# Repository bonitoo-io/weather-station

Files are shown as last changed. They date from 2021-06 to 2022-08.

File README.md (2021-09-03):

# Weather Station

## Description

Weather station is a smart IoT device that shows various information on the embedded OLED display.



It can show the following information:

- Actual `time and date` (in analog and digital format). Accurate time and date is automatically loaded from NTP time service.
- Current `temperature` and `humidity` using internal sensor
- `Temperature chart` showing trend for the last 90 minutes. If the temperature is stored into InfluxDB, after rebooting this temperature history is fully loaded back from the InfluxDB.
- `Current weather` - shows weather icon, temperature, and wind speed. It automatically identifies approximate location for weather service based on assigned IP address. The weather is updated once per hour.
- `Weather forecast` for the next three days at noon - shows weather icon, temperature, wind speed and wind direction
- `Moon phase`, moon set/rise and sun set/rise time

To get time, location, weather forecasts and other information, the weather station requires Internet connection over WiFi. The temperature and humidity from the internal sensor can be also automatically stored into InfluxDB to analyze history.
Information on the OLED display can be localized. Currently we support English and Czech language. The weather station firmware is checked once per day and in case of new firmware, it is automatically updated from the centralized repository.
The weather station is powered via USB cable.

## QuickStart Guide

### WiFi Connection

Weather station requires WiFi network (to get time/date, weather forecast, to store temperature/humidity history, etc.)
Because it does not have any keyboard to configure it, the Weather Station requires your mobile phone or computer to set it up. It creates own WiFi hotspot to connect it by your device.

WiFi Configuration steps:

1) Plug USB cable into the Weather Station to power on. If your computer shows missing driver message, you can ignore it.
2) The Weather Station shows a name of WiFi network for configuration that is created by the Weather Station itself. If you see Connecting WiFi message, and the Weather Station is unable to connect, please wait for 30 seconds to show the WIFi network.
3) Connect your phone or laptop to this WiFi. No password is required.
4) If the phone or laptop shows that the WiFi does not offer Internet connection, please ignore it and confirm the connection - the WiFi was created just for configuration of the Weather Station
5) A configuration page should be displayed automatically. If not, open your browser and type <http://1.1.1.1> In both cases you should see Weather Station web page.
6) Select your home/company WiFi network from the list that Weather Station can connect. The list is sorted from the strongest one. If your WiFi network is hidden, please enter the name (SSID) manually via link. Note that only 2.4GHz WiFi networks are supported.
7) Enter your WiFi network password, if exists
8) Click to Save button
9) The Weather Station should reboot and sync all the data via the newly configured WiFi. Your phone or laptop should be disconnected automatically.
10) If you see again the same message on the OLED display as in the second step, the network name or password has been entered incorrectly. Please repeat the process.

### InfluxDB Configuration

If you want to record your temperature and humidity measured by the Weather Station sensor, you need to setup an InfluxDB account.
You can also use a free [InfluxDB Cloud](https://cloud2.influxdata.com) account, or you can deploy your own InfluxDB instance. Additionally, the Weather Station also records into InfluxDB some run-time measurements like free memory, heap fragmentation, reboot reason, firmware version or uptime.
The following steps require a Weather Station with properly connected WiFi network (see the previous chapter).

InfluxDB Configuration steps:

1) Wait for the last page on the OLED display
2) Enter into the web browser on your phone or computer the address from the last page
3) Your browser should show Weather Station web page. Note that your phone or computer must be connected to the same WiFi network as the Weather station otherwise you cannot open it.
4) Select InfluxDB Settings from the menu
5) Fill all required fields (specific bucket must be created in the InfluxDB as well as token with read/write access)
6) Click to Save button
7) If you see an exclamation mark icon in the top left corner of the OLED display, the fields are not entered correctly, or Weather Station lost the connection to the InfluxDB.

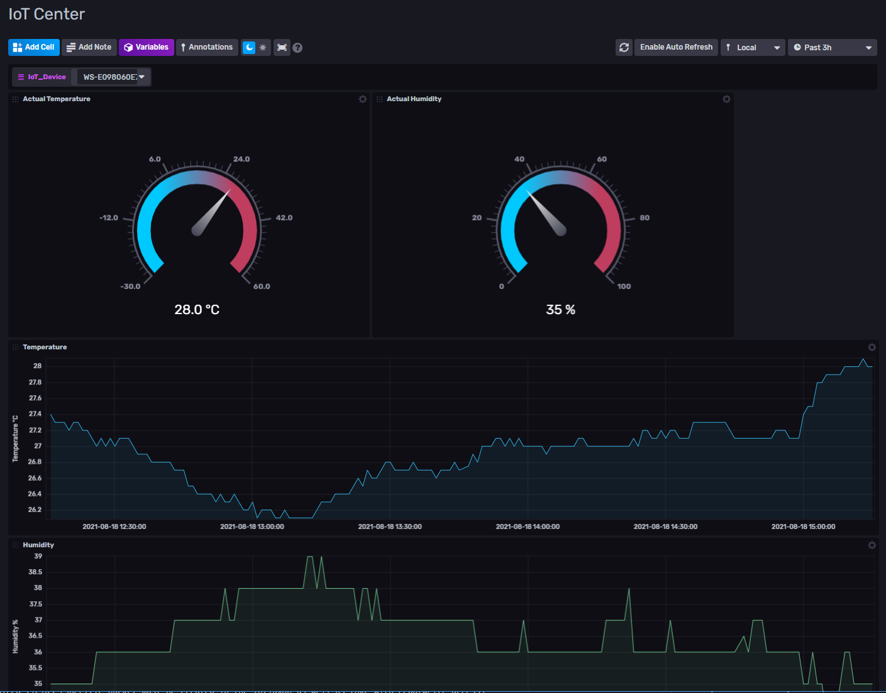
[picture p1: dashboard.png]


## Technical part

### Hardware

Developed for Weather Station DIY kit that consists of:

- `IoT Platform` - [ESP8266](https://docs.ai-thinker.com/_media/esp8266/docs/esp-12f_product_specification_en.pdf)
- `Display` - OLED 0,96" 128x64 [SSD1306](https://cdn-shop.adafruit.com/datasheets/SSD1306.pdf)
- `Temperature and Humidity sensor` - [DHT11](https://www.mouser.com/datasheet/2/758/DHT11-Technical-Data-Sheet-Translated-Version-1143054.pdf)

### Source Code

The Weather Station project consists of three sub-projects:

1) [Full Arduino Implementation](arduino/WeatherStation#weather-station)
2) [Basic Micropython Implementation](micropython)
3) [Case for 3D Printer](case)

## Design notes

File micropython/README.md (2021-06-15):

# Micropython ESP8266 Weather Station

## Description

This is PoC Weather Station project written in Micropython language for ESP8266 device. 
It is designed to show possibilities and limits of current Micropython firmware 
and implement a simple InfluxDB2 Client with timestamp support. In order to have relatively accurate timestamps it also 
implements periodic RTC synchronisation with NTP server. OLED display 
(using included micropython's DHT11 and SSD1306 driver) shows DHT11 data with random screen coordinates
to avoid screen burn-in.



It consists of:
  - `config.json` - JSON objects with configuration.
  - `webrepl_cfg.py` - WebREPL configuration. 
  - `boot.py` - Micropython boot file.
  - `main.py` - Micropython main code.
  - `wm.py` - Wi-Fi Manager to allow automatic wi-fi connections according to _known_networks_ entries in `config.json`. 
  In case of no _known_networks_ available it is also capable of running private access point with WebRepl.

## How to run the Micropython WeatherStation

1) Flash the firmware.
2) Install python shell.
3) Update `config.json`:
    - configure wi-fi connection details (With Internet connection for NTP routine)
    - add your influxdb2 connection details
    - adjust intervals
4) Set password for WebREPL connection in `webrepl_cfg.py`  
4) Adjust Point object parameters to reflect your infrastructure:
   ```python
   def publish(data, client):
    point = Point("dht11") \
        .field("temperature", data["t"]) \
        .field("humidity", data["rh"]) \
        .tag("location", "office") \
        .time(time.time(), WritePrecision.S)
   ...
   ```
   - Available functions for getting time:
     https://docs.micropython.org/en/latest/library/utime.html#module-utime
     
5) Connect to the device.
6) Put all files into device.
7) Restart WeatherStation device.

## Firmware

Before execution of any micropython code each ESP device must be erased and flashed with latest micropython firmware.

How-To Guide: https://micropython-docs-esp32.readthedocs.io/en/esp32_doc/esp8266/tutorial/intro.html#intro

Download page: https://micropython.org/download/esp8266/

## Remote shells

Used to manipulate with files and run python code over serial connection.

Top 3 shells to choose from:

Ampy: https://github.com/scientifichackers/ampy

Mpfshell: https://github.com/wendlers/mpfshell

Rshell: https://github.com/dhylands/rshell

## Caveats

### SSL error (OSError -40):

With Micropython's ESP8266 port version (=< 1.15) the https post to cloud2.influxdata.com fails with OSError -40. 
The issue seems to be that certain certificate types are not supported in axtls of underlining ESP-SDK.
Only solution seems to be wait until micropython will be supporting newer ESP-SDK with mbedtls, 
or compile your own micropython firmware with a hack described in:  
https://github.com/micropython/micropython-lib/issues/400

More details: https://docs.micropython.org/en/latest/esp8266/general.html#ssl-tls-limitations

### NTP time in UTC only:

There's currently no timezone support in MicroPython (1.15) for ESP8266 port, and the RTC is set in UTC time.

### Internal Real-time Clock limits:

RTC in ESP8266 has very bad accuracy, drift may be seconds per minute. 
As a workaround, to measure short enough intervals you can use utime.time(), etc. 
and/or synchronise time via ntp regularly. 
Due to limitations of the ESP8266 chip the internal real-time clock (RTC) will overflow every 7:45h. 
If a long-term working RTC time is required then time() or localtime() must be called at least once within 7 hours. 
MicroPython will then handle the overflow.

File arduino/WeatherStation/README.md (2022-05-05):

# Weather Station

Weather station with OLED and WiFi (using ESP8266, SSD1306, and DHT11) with InfluxDB support

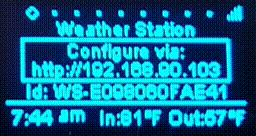
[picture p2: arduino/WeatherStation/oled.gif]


## Arduino IDE

* Into "File/Preferences/Additional Boards Manager URLs:" add "http://arduino.esp8266.com/stable/package_esp8266com_index.json"
* Menu Tools/Board:/Boards Manager select esp8266 and Install it
* Select Tools/Board: NodeMCU 1.0 (ESP-12E Module)
* Connect weather station via USB
* Select Tools/Port: the serial port created by the weather station
* Open WeatherStation.ino file
* Update OPEN_WEATHER_MAP_API_KEY
* Click the secon icon in the toolbar "Upload"

* Create iot_center bucket inside InfluxDB

## Required Libraries

Libraries are accessible via Library manager or must installed manually, if source URL is provided.
Indentation means transitive dependency, but such a library must be installed as well.

* ESP8266 and ESP32 OLED driver for SSD1306 displays (by ThingPulse, Fabrice Weinberg)
* ESP8266 Weather Station (by ThingPulse) optimized version - from https://github.com/bonitoo-io/esp8266-weather-station branch [all-fixes](https://github.com/bonitoo-io/esp8266-weather-station/tree/all-fixes)
  * Json Streaming Parser (by Daniel Eichhorn)
* Support for Sensirion's humidity and temperature sensors - Supported sensors: SHTC1, SHTC3, SHTW1, SHTW2, SHT3x-DIS (I2C), SHT85, SHT3x-ARP, SHT4x
  * arduino-sht
* ESP8266 Influxdb (by Tobias Schürg, InfluxData)
* ESP Github Updater - from https://github.com/bonitoo-io/ESP-Github-Updater
* ESPAsyncWebServer - from https://github.com/bonitoo-io/ESPAsyncWebServer/ branch [feat/global_filter](https://github.com/bonitoo-io/ESPAsyncWebServer/tree/feat/global_filter)
  * ESPAsyncTCP - from https://github.com/bonitoo-io/ESPAsyncTCP

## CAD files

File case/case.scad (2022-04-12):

// case Roman

// won't change result just render faster but can result in visual bugs in preview                                       ------------
fast_render = true; 

render_parts = "all"; // ["all": All, "box": Box, "cover": Cover, "button": Button, "none": none, "display": Display test, "cover-test": Cover test , "hexbox1": Hexbox vizualization, "hexbox2": Hexbox vizualization 2]

/* [Shell] */

shell_width = 1.5; // [.2:.1:3]

outer_fillet = 3.3;
inner_fillet = 1;

// hex recomended logo_position_x = 14.5;
logo_position_x = 1; // [-12:.5:28]
// hex recomended logo_position_y = -24.2;
logo_position_y = -24; // [-28:.5:12]
// hex recomended logo_scale = 1;
logo_scale = 1.15; // [.5:.01:1.5]

// previous usb_hole = [9.5, 3.8];
usb_hole = [14.2, 5.5];

/* [Main board] */
corner_width = 5;
corner_support = 7;
board_height_modificator = -.5;

/* [Hex] */
hex_enabled = true;

hex_front = false;
hex_right = true;
hex_left = true;
hex_top = false;
hex_bot = false;
hex_sensor_wall = false;

hex_dist = 1.25;
shell_critical_places_dist = 1.5;

/* [Button] */
// button changes based on shell width
button_use_shell_width = true; 
// button stand out when use shell width enabled
button_height_shell_added = .2;
// bottom cylinder of button, this changes socket too
button_height = 4;
// height of securing cylinder preventing button from falling out
button_height2 = 3;
// width of button visible from outside
button_width = 3;
// upper width of securing cylinder, must be higher than button width
button_width2 = 4;
// width of slip-preventing button to board contact
button_width3 = 4;
// full height of button, can be dependent on button_use_shell_width
button_height_full = 24;
// distance between button and socket
button_clearance = .15;
// how strong is button socket
button_socket_width = .8;

/* [Ventilation] */
vent_top = false;
vent_side = false;
vent_upper_width = 7;
vent_upper_dist_side = 2;

/* [Sensor wall] */
sensor_wall_width = 1.5;
sensor_wall_hole_width = 3;
sensor_wall_hole_height = 50;

/* [Cover] */
cover_lock_clearance = [ 2, .1, .4 ];
use_cover_text = false;
cover_frame_polygon = [[0, 0], [3, 0], [0, 5]];
// y=0 will use shell width
box_cover_lock = [20, 0, .8]; 
batch_number = "2203";

module _() {}
// vnitřní rozměry v mm
w = 58.5;  // inner Width
d = 58.5;  // depth
h = 29;    // height

main_board_width = 43.75;
main_board_depth = 57;

logo_position = [logo_position_x, logo_position_y];

box_cover_lock_real = [box_cover_lock[0], box_cover_lock[1] == 0 ? shell_width : box_cover_lock[1], box_cover_lock[2]];

if (render_parts == "all") {
  translate([-(w / 2) - shell_width - 1, 0, 0])
  {
    ws_box(hex= hex_enabled);

    translate([w / 2 + shell_width + button_width2 + 2, h + button_width2 + 2, 0])
      button();

    translate([w+shell_width+2,0,0])
      cover();
  }
}

if (render_parts == "box") {
  ws_box(hex= hex_enabled);
}

if (render_parts == "cover") {
  cover();
}

if (render_parts == "button") {
  button();
}

*
translate([-15,-15,0]) {
  difference() {
    union () {
      cube([30,30,30]);

      translate([30+.3, 0, 0])
      translate([0, 1, 1])
      rotate(-90, [0,1,0])
      scale([.8, .8])
      linear_extrude(.3+1)
        {
          import("logo_influx.svg");
  
          mirror([0,1,0])
          rotate(-90)
              text(".3 out side", size=2, $fn=1);
        }

      translate([1, 1, 30 - 1])
      scale([.8, .8])
      linear_extrude(.8+1)
        {
          import("logo_influx.svg");
          text(".8 out top", size=2, $fn=1);
        }

    }

    translate([1,1,-1])
    linear_extrude(.8+1)
      translate([28,0,0])
      mirror([1,0,0])
      scale([.8, .8]){
        import("logo_influx.svg");
        text(".8 in bot", size=2, halign= "left", $fn=1);
      }

    translate([.3, 1, 1])
    rotate(-90, [0,1,0])
      linear_extrude(.3+1)
      scale([.8, .8])
      {
        import("logo_influx.svg");
        rotate(-90)
            text(".3 in side", size=2, halign= "right", $fn=1);
      }
    translate([2,-1,2])
      cube ([26,32,25]);
  }
}

if (render_parts == "display")
  translate([7, -10, 0]) {
    intersection() {
      ws_box();
      translate([-24,-5,0])
        cube([33,32,8]);
    }
  }

if (render_parts == "hexbox1")
translate() {
  ws_box(hex= false);
  %
  shellCriticalPlaces();
}

if (render_parts == "hexbox2")
translate() {
  %
  ws_box(hex= false);
  hex_cuts();
}



// box cover test
if (render_parts == "cover-test")
translate([-(w / 2) - 2, 0, 0]) {
  difference(){
    cover();
    translate([0, 0, -1]) 
      cube_center_xy([w-10,d-10,20]);
    translate([0, -1, -1]) 
      cube_center_xy([5,d-9,20]);
  }

  translate([w + shell_width * 2 + 2, 0, 0])
  {
    translate([0,0,2])
      box_cover_frame();
      
    difference() {
      cube_center_xy([w + shell_width * 2, d + shell_width * 2, 2], 2);
      difference() {
        translate([0,0,-1])
          cube_center_xy([w, d, 2 + 2], fillet= 2);
      }
    }
  }
}

module hex_wall_3d (size= 6, dist= 1, h= 1, rows= 10, cols= 10) {
  w = size * sqrt(3);
  hex_h = 2 * size;
  h_dist = hex_h * 3 / 4;

  translate([size, w / 2, 0])
  for (col = [0:(cols-1)]) {
    even_col = (col % 2) == 0;
    translate([0, even_col ? 0 : w / 2, 0])
    for(row = [0:(rows-1)]){
      translate([h_dist * col, w * row, 0])
        cylinder(h, size-dist, size-dist, $fn= 6, center= false);
    }
  }
}

module hex_wall_2d (size= 6, dist= 1, rows= 10, cols= 10) {
  w = size * sqrt(3);
  hex_h = 2 * size;
  h_dist = hex_h * 3 / 4;

  translate([size, w / 2])
  for (col = [0:(cols-1)]) {
    even_col = (col % 2) == 0;
    translate([0, even_col ? 0 : w / 2])
    for(row = [0:(rows-1)]){
      translate([h_dist * col, w * row])
        circle(size-dist, $fn= 6);
    }
  }
}

module hex_wall(size= 6, dist= 1, h= 1, rows= 10, cols= 10) {
  if (fast_render)
    linear_extrude(h)
      hex_wall_2d(size=size, dist=dist, rows=rows, cols=cols);
  else 
      hex_wall_3d(size=size, dist=dist, h=h, rows=rows, cols=cols);
}


// Single layer experiment

// shell_width = .5;
// outer_fillet = 1;
// inner_fillet = 4;

// rest_height = .16;
// bottom_support_height = 1;
// bottom_support_Width = .8;
// bottom_support_fillet = 4;

// translate([0,0, - 1.5 + rest_height])
// difference() {
//   union() {
//     ws_box();

//     translate([ 0, 0, 1.5 - .1 + rest_height ])
//     difference(){
//       $fn= 50;
//       minkowski() {
//           cube_center_xy([ 
//             w - inner_fillet * 2, 
//             d - inner_fillet * 2, 
//             bottom_support_height - .01
//           ]);
//         cylinder(r = inner_fillet, h = .01);
//       }
//       translate([0,0,-1])
//       minkowski() {
//           cube_center_xy([ 
//             w - bottom_support_fillet * 2 - bottom_support_Width * 2, 
//             d - bottom_support_fillet * 2 - bottom_support_Width * 2, 
//             bottom_support_height + 2
//           ]);
//         cylinder(r = bottom_support_fillet, h = .01);
//       }
//     }
//   }

//   translate([0,0,-2])
//     cube_center_xy([100, 100, 1.5 + 1 - rest_height]);
// }



module cube_center_xy(sizes, fillet, $fa = 1, $fs = .1) {
  if (!fillet) {
    translate([ -sizes[0] / 2, -sizes[1] / 2, 0 ]) cube(sizes);
  } else {
    minkowski() {
      cube_center_xy([ sizes[0] - fillet * 2, sizes[1] - fillet * 2, sizes[2] - .0001]);
      cylinder(r = fillet, h = .0001);
    }
  }
}

module shellCriticalPlaces (dist= 2){
  // button hole
  translate([ 12, 19, -1 - shell_width + 1.5 ]) 
    cylinder(r = 4 + dist, h = shell_width + 2, $fn = 60);

  // display
  translate([ -7.5, 11, -1 - shell_width + 1.5 ]) 
  difference()
  {
    linear_extrude(shell_width + 2)
      square([ 29 + 2.5 + dist * 2, 28 + 2.5 + dist * 2 ], true);

    translate([ 0, 0, -2 ]) {
      cube_center_xy([ 27 - dist * 2, 26 - dist * 2, shell_width + 2 + 2 ]);
      cube_center_xy([ 20 - dist * 2, 40 - dist * 2, shell_width + 2 + 2 ]);
      cube_center_xy([ 40 - dist * 2, 20 - dist * 2, shell_width + 2 + 2 ]);
    }
  }
  translate([ -20.5 - dist, 2 - dist, -0.7 - shell_width + 1.5 ]) 
    cube([ 25 + dist * 2, 14 + dist * 2, shell_width + 5 ]);

  // corners
  translate([0, 0, -1])
  difference() {
    translate([0,0,-(shell_width - 1.5)])
      cube_center_xy([ w + shell_width * 2 + 2, d + shell_width * 2 + 2, h + 1 - 2 + 2 + 2 +(shell_width - 1.5) ]);
    translate([ 0, 0, 1.5 + dist ]){
      cube_center_xy([ w+10 + shell_width * 2, d-dist*2, h-dist * 3 ]);
      cube_center_xy([ w-dist*2, d+10 + shell_width * 2, h-dist * 3 ]);
    }
    translate([0,0,-1 - (shell_width - 1.5)])
      cube_center_xy([ w-dist*2, d-dist*2, h+1.5+10 + (shell_width - 1.5) ]);
  }

  // main board holder
  translate([ -w / 2 + main_board_width / 2 + 1, 0, h - 10 + board_height_modificator])
  difference() {
    cube_center_xy([ main_board_width + 2 + dist * 2, main_board_depth + 2 + dist * 2 + 2 * 2 + shell_width*2, 10 ]);
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

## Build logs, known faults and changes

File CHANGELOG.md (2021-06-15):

## v0.9 [2021-0x-xx]

### Features

### Fixes

1. [#2](https://github.com/bonitoo-io/weather-station/pull/2): **linux**: Tools.h must be case sensitive
2. [#5](https://github.com/bonitoo-io/weather-station/pull/5): **cloud2**: lowercase lat and lon, fix SFO GPS location

### Other

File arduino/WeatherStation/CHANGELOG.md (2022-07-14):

# Changelog
## 1.15
### Fixes
 - Fixed updating data in the night mode
 - Improved writing stability when weak WiFi connection 
 
## 1.14
### Fixes
 - Improved wifi settings persistance to allow WiFi network name with slash char

## 1.13
## Fixes
 - Improved Web server response
 - Improved stability
 - Improved memory footprint
 - Optimized settings validations
 - Faster switch from AP mode
 - Added geo location fallback when Weather Forecast is not available for city

## 1.12
## Fixes
- Fixed temp offset calculation in calibration

## 1.11
## Features
- Support for all Sensirion SHT* sensors
  - Automatic detection
- Improved OLED config screen
## Fixes
- WebUI
  - More robust data requests to server
  - Occasional WiFi scanning error
  - Skip validations when device is in AP mode

## 1.10
## Features
 - Sensor Calibration Dialog

## 1.05
## Features
 - Display Night Mode
## Fixes
 - Faster initial WiFi reconnection
 - Improved web server response caching

## 1.01
## Fixes
  - Fixed limit on list of scanned WiFi networks
  - Updated Github certificate for firmware download
  - Firmware update does not verify certificate by default
  - Reliable web server start after regional settings update
## 1.00
## Features
 - Restructured settings UI
  - Introduced Display settings
  - Update setting moved to Advanced settings
## Fixes
 - Non-latin languages forced to English

## 0.59
## Features
 - Improved OLED debug screen
 - Added repeated resets check
## Fixes
 - Trying update weather info more times

## 0.58
 - Fixed update version comparing

## 0.58-rc9
## Fixes
- Fixed update version comparing

## 0.58-rc8
## Fixes
 - Improved Web UI validation messages
 - Improved DB write error handling
 - Fixed occasionally missing tags
 - Fixed update version comparing

## 0.58 rc7
## Features
 - Sensirion SHTC3 temperature and humidity sensor support
 - Autocalibration of DHT11
## Fixes
 - Improved initial WiFi settings behavior
 - Fixed HTTP server response on cached URL
 - Improved Web UI validation messages

## 0.58 rc6
## Features
 - Dual color OLED support
 - Humidity offset autocalibration (when offset is 0)
 - Auto-reboot when InfluxDB write fails for the whole hour
## Fixes
 - Memory optimization
 - IP loc detection reloads country specific settings when location is unchanged

## 0.58 rc5
## Features
 - InfluxDB client with streaming write
 - Web Server improvements:
   - All request logging
   - No cache for api responses
   - Concurrent writing and api request check
   - All UI requests to server handle 503 and 427
  - Added Covid-19 OLED screen

## 0.58 rc4
## Fixes
 - InfluxDB Client with fixed disabled retrying
 - Decreased batch size
 - Increased HTTP timeout

## 0.58 rc3
## Fixes
 - Reverting InfluxDB Client to the latest release

## 0.58 rc2
## Features
 - New application icon
 - Reporting WiFi reconnects count
## Fixes
 - Detecting UTC offset change always
 - Improved stability

## 0.58 rc1
## Fixes
 - Improved initial web page loading
 - Using memory optimized InfluxDB Client

## 0.57 [2021-10-12]
## Features
 - Split Status page to About and Status
   - Added automatic refresh to Status page
 - Added monitoring of synchronization services
 - Added Advanced Settings
   - Including ability to configure display screens

## Fixes
 - Fixed setting configure language after reset
 - Improved web server response stability

## 0.56 [2021-09-30]
 - Improved WiFi setting wizard
   - Improved on-screen instruction
   - Initial landing page when WiFi is not working is WiFi Scanner
   - WiFi signal strength is shown in percents
 - Added readme with user guide
 - Smoother app icon
 - Added Updater Settings
 - Added WiFi network management
   - Each connected network is remembered
 - Added Regional Settings
   - Possibility to disable location detection
   - Manual setting of regional parameters
 - Allowing upload firmware via web interface

## 0.55
 - Added validation of WiFi params during initial configuration
 - Simplified on screen setup instructions
 - Removed passwords from debug output
 - Using [custom memory optimized esp8266-weather-station library fork](https://github.com/bonitoo-io/esp8266-weather-station)
 - Web server is shut down during updating data to save RAM

## 0.54
 - InfluxDB Settings token obfuscation
 - WifiScan page improved
 - Built with SDK 3.0.0

## 0.53
 - Display improvements
 - About temperature unit fix
 - Added writing of device status

## 0.52
 - Fixing on time update issue (#13)

## 0.51
 - About page
 - Display improvement

## 0.50
 - InfluxDB server settings web UI

## 0.49
 - Updating from github using template file name and MD5 checksum - version 1.0.0 of ESP-GitHub-Updater is required

## 0.48
 - OTA updates from github

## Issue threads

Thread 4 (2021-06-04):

Geo Location data are not consumable by cloud2 ui

ivankudibal, 2021-06-04:
Geo Location data are not consumable by cloud2 UI

1. Create Geo Map in the Cloud2 for the data from weather station
2. Use the component

Here's the query
```js
from(bucket: "iot_center")
  |> range(start: v.timeRangeStart, stop: v.timeRangeStop)
  |> filter(fn: (r) => r["_measurement"] == "environment")
  |> filter(fn: (r) => r["_field"] == "Lat" or r["_field"] == "Lon")
  |> aggregateWindow(every: v.windowPeriod, fn: mean, createEmpty: false)
  |> last()
  |> yield(name: "mean")
```

Yields the error when I want to save the Map on my dashboard

"Map type is not supported with the data provided. Map type only supports latitude/longitude values (field values must be specified to either lat or lon)"

..
also the default geo location of SF should be -122, the current longitude is 122 -> this will place the marker somewhere into Asia

Closed 2021-06-15.

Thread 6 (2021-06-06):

Unit should be written to influxdb, too

ivankudibal, 2021-06-06:
A unit in general should be written to Influxdb, too.

Temperature is configurable, degrees of Fahrenheit or Celsius. The data written to influxdb contain just a number.

It would be useful to know the unit in order to

1. use temperature  numbers from two stations in one chart
2. historical data in one device can be stored in two different units (uc: device reconfiguration)

devmirek, 2021-06-17:
Added TemperatureUnit tag to specify unit, it is always C

Closed 2021-06-17.

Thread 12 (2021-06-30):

Update didn't run on specific time

vlastahajek, 2021-06-30:
The device configured to be updated at 3:00 was not updated, even a new version was available.
Update proceeded successfully on restart.

vlastahajek, 2021-06-30:
The problem is in low memory. Update check is started and it founds an update, but actual update download couldn't be started.

Closed 2021-06-30.

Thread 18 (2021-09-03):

Wifi connection restore

devmirek, 2021-09-03:
Device should periodically try to restore current WiFi connection when it is in AP mode to recover form WiFi connection drops.

vlastahajek, 2021-09-03:
This is how it works from the beginning.
If there is a WiFi config and WiFi is not connected and the last error is not "authorization fail", a reconnection attempt is made each 30s, even AP is running.
The issue can be the device is simply not able to connect to WiFi, from an unknown reason.

vlastahajek, 2021-09-08:
As tested at home, where the device was not able to connect to WiFi, after several hours I found the device was connected. This confirms the periodic reconnection works.

Closed 2021-09-08.

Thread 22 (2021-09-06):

Remember already connected WiFi networks

devmirek, 2021-09-06:
Currently the device supports only one WiFi network. It should support multiple networks like Windows/Android/IOS. The WiFi settings page should contain list of all known WiFi networks with option to remove it. Connecting of new WiFi network should add this network into the list after successful connection. The REST API should never return any WiFi password.

vlastahajek, 2021-10-03:
Multi Wifi implemented in #25 and improved in #26.
TODO: remove wifi password from REST.

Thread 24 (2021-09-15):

Captive portal support

devmirek, 2021-09-15:
WiFi network with required captive portal causes inability to access weather station and access Internet services.  Weather station should check Internet connection status and if Internet doesn't work, the station should select another WiFi or switch to AP mode.

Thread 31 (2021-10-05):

Screen configuration

devmirek, 2021-10-05:
Add to the device configuration web:

- skip selected screens
- screen timeout
- screen language

vlastahajek, 2021-10-05:
> screen language

Language is already part of Regional settings and it controls the language of the screen. So, where the Language should be?

Also, the current plan is to have screens configuration part of the Advanced settings UI. Does it need a separate config UI?
The optimal number of setting screens is 4 (to nicely fit on a mobile screen). Existing setting screens are _InfluxDB, Update, Regional_ and planned Advanced.

vlastahajek, 2021-10-05:
> screen timeout

Timeout is a bit negative word. What about screen change/switch/refresh interval?

devmirek, 2021-10-05:
Timeout = setTimePerFrame()
This issue does not require a dedicated configuration for screen. Just make sure, that we cover the all screen settings.

vlastahajek, 2021-10-05:
|  skip selected screens

Seems a bit confusing to select items not to see.  Why not just _Visible Screens_?

devmirek, 2021-10-05:
Strings:

Screen rotate interval [ms]:
Show screens [letters]:
_Screens (letter is in brackets): (A)nalog time; (D)igital time; (I)ndoor temperature/humidity; (T)emperature chart; (O)utdoor weather; weather (F)orecast; (W)ind forecast; (M)oon phase rise/set; (C)onfiguration info_

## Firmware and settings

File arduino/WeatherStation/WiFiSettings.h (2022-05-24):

#ifndef WS_WIFI_SETTINGS_H
#define WS_WIFI_SETTINGS_H

#include <ESP8266WiFi.h>
#include <AsyncJson.h>
#include <ESPAsyncWebServer.h>
#include "Settings.h"
#include "FSPersistance.h"
#include <vector>

#define DEFAULT_WIFI_SSID ""
#define DEFAULT_WIFI_PASSWORD ""

#define WIFI_CONFIG_DIRECTORY FS_CONFIG_DIRECTORY "/wifi"
#define WIFI_HOSTNAME_PREFIX "weather-station-"
#define WIFI_SETTINGS_ENDPOINT_PATH "/api/wifiSettings"
#define WIFI_SETTINGS_OLD_FILE_NAME "wifiSettings.json"

extern const char *StringSSID;

class WiFiSettings : public Settings {
  public:
    // main configuration
    String ssid;
    String password;
    String hostname;
    bool staticIPConfig;
    // optional configuration for static IP
    IPAddress localIP;
    IPAddress gatewayIP;
    IPAddress subnetMask;
    IPAddress dnsIP1;
    IPAddress dnsIP2;
  private:
    String _filePath;
  public:
    WiFiSettings();
    void setFilePath(const String &filePath) { _filePath = filePath; }
    virtual int save(JsonObject& root) override;
    virtual int load(JsonObject& root) override;
    virtual void print(const __FlashStringHelper *title) override;
    virtual String getFilePath() override { return  _filePath; }
  private:
    static char *DefaultHostname;
};

class WiFiSettingsManager {
public:
  WiFiSettingsManager(FSPersistence *pPersistence);
  bool saveSettings(WiFiSettings *pSettings);
  bool loadSettings(WiFiSettings *pSettings, const String &ssid);
  void removeSettings(const String &ssid);
  std::vector<String> listSavedWiFiNetworks();
  int savedWiFiNetworksCount();
private:
  // Finds config file for WiFi network with ssid
  String findConfigWithSSID(const String &ssid);
  // Finds file name for WiFi network with ssid
  String filenameForSSID(const String &ssid);
private:
  FSPersistence *_pFsp;
};

class WiFiSettingsEndpoint : public SettingsEndpoint {
  public:
    WiFiSettingsEndpoint(FSPersistence *pPersistence, Settings *pSettings);
};

#endif //WS_WIFI_SETTINGS_H

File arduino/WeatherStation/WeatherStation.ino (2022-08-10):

/*
Board: Lolin D1 mini (clone) (ESP-12E Module)
Executable segment sizes:
ICACHE : 32768           - flash instruction cache
IROM   : 957188          - code in flash         (default or ICACHE_FLASH_ATTR)
IRAM   : 29565   / 32768 - code in IRAM          (IRAM_ATTR, ISRs...)
DATA   : 1716  )         - initialized variables (global, static) in RAM/HEAP
RODATA : 8140  ) / 81920 - constants             (global, static) in RAM/HEAP
BSS    : 28040 )         - zeroed variables      (global, static) in RAM/HEAP
Sketch uses 996609 bytes (95%) of program storage space. Maximum is 1044464 bytes.
Global variables use 37896 bytes (46%) of dynamic memory, leaving 44024 bytes for local variables. Maximum is 81920 bytes.
*/

#include <Arduino.h>
#include <ESPWiFi.h>
#include <SSD1306Wire.h>
#include <OLEDDisplayUi.h>
#include "WeatherStation.h"
#include "InfluxDBHelper.h"
#include "Tools.h"
#include "Updater.h"
#include "Sensor.h"
#include "Debug.h"
#include "Version.h"
#include "ServiceState.h"
#include "ScreenCommon.h"
#include "WiFi.h"

// IoT Center url, e.g. http://192.168.1.20:5000  (can be empty, if not configured)
#define IOT_CENTER_URL ""

// Button and LED
#define PIN_LED    D2   //LED pin  GPIO4
#define PIN_BUTTON D3   //Boot button pin  GPIO0
// I2C settings
#define PIN_SDA    D4   //GPIO2
#define PIN_SCL    D5   //GPIO14
#define I2C_OLED_ADDRESS 0x3c
#define DEFAULT_DELAY 50  //50ms max CPU delay in loop

#include "custom_dev.h" //Custom development configuration - remove or comment it out

tConfig conf = {
//TODO: move iot center config to web config
  IOT_CENTER_URL, //iotCenterUrl
  60             //iotRefreshMin
};

// Initialize the oled display
SSD1306Wire display(I2C_OLED_ADDRESS, PIN_SDA, PIN_SCL);
OLEDDisplayUi ui( &display);

InfluxDBHelper influxdbHelper;

// Weather station backend
WeatherStation station(&influxdbHelper);
Updater updater;


unsigned long timeSinceLastUpdate = 0;
unsigned int lastUpdateMins = 0;
String resetReason;
unsigned long nextUIUpdate = 0;
bool skipNightScreen = false;


void updateData(OLEDDisplay *display, bool firstStart);
bool loadIoTCenter( bool firstStart, const String& iot_url, const char *deviceID, InfluxDBSettings *influxdbSettings, unsigned int& iotRefreshMin, float& latitude, float& longitude);
int detectLocationFromIP(RegionalSettings *pRegionalSettings);
bool updateClock(int utc_offset, const String &ntp);
bool updateAstronomy(bool firstStart, const float lat, const float lon);
bool updateCurrentWeather(RegionalSettings *pRegionalSettings, const String& APIKey);
bool updateForecast( RegionalSettings *pRegionalSettings, const String& APIKey);
void drawNight(OLEDDisplay *display, DisplaySettings *pDisplaySettings);
uint8_t isNightMode( DisplaySettings *pDisplaySettings);

void initData() {
  if(!(wsState & WSState::AppStateInitialised) && WiFi.isConnected() && !(wsState & WSState::AppStateAPRunning)) {
    WS_DEBUG_RAM("InitData");
    updater.init(station.getAdvancedSettings(), VERSION);

    //Initialize OLED UI
    initOLEDUI(&ui, station.getDisplaySettings());
    if(resetReason.length()) {
      influxdbHelper.registerResetInfo(resetReason);
      resetReason = (char *)nullptr;
    }
    ServicesTracker.reset();

    //Load all data
    updateData(&display, true);

    wsState |= WSState::AppStateInitialised;
  }
}

void setup() {
  // Prepare serial port
  Serial.begin(115200);
  delay(1000);
  Serial.println();
  Serial.println();

  ESP.wdtEnable(WDTO_8S); //8 seconds watchdog timeout (still ignored)
  Serial.println(F("Starting Weather station v" VERSION " built " __DATE__ " " __TIME__));
  WS_DEBUG_RAM("Setup 1");

  if(ESP.getResetInfoPtr()->reason != REASON_DEEP_SLEEP_AWAKE) {
    resetReason = ESP.getResetReason();
    Serial.print(F(" Reset reason: "));
    Serial.println(resetReason);
  }

  ServicesTracker.load();

  //Initialize OLED
  display.init();
  display.clear();
  display.display();

  // Configure pins
  pinMode(PIN_BUTTON, INPUT);
  pinMode(PIN_LED, OUTPUT);
  digitalWrite( PIN_LED, HIGH);

  Serial.print(F("WS crash reset count: "));
  Serial.println(ServicesTracker.getResetCount()-1);

  // repeated reset - wait
  if(ServicesTracker.getResetCount() > 3) {
    for(int i=0; i<100;i++) {
      drawUpdateProgress(&display, i, getStr(s_Reset_wait));
      if (digitalRead(PIN_BUTTON) == LOW) //skip if BOOT button is pressed
        break;
      delay(1000);
    }
  }

  station.getWifiManager()->setWiFiConnectionEventHandler(wifiConnectionEventHandler);
  station.getWifiManager()->setAPEventHandler(wifiAPEventHandler);

  station.getInfluxDBSettings()->setHandler([](){
    wsState |= WSState::AppStateSetupInfluxDB;
  });

  station.getAdvancedSettings()->setHandler([](){
    if(station.getAdvancedSettings()->updatedParts & AdvancedSettingsParts::UpdateSettings) {
      updater.init(station.getAdvancedSettings(), VERSION);
    }
    if(station.getAdvancedSettings()->updatedParts & AdvancedSettingsParts::OpenWeatherAPIKey) {
     wsState |= WSState::AppStateForceUpdate;
    }
    if(station.getAdvancedSettings()->updatedParts & AdvancedSettingsParts::Offsets) {
      // Must be done in the main loop
      wsState |= WSState::AppStateSetOffsets;
    }
  });

  RegionalSettings *pRegionalSettings = station.getRegionalSettings();
  pRegionalSettings->setHandler([pRegionalSettings](){
    if(((pRegionalSettings->updatedParts & RegionalSettingsParts::DetectAutomatically) && pRegionalSettings->detectAutomatically)
      || (pRegionalSettings->updatedParts & RegionalSettingsParts::UtcOffset)
      || (pRegionalSettings->updatedParts & RegionalSettingsParts::City)) {
      wsState |= WSState::AppStateForceUpdate;  
    }
    if(pRegionalSettings->updatedParts & RegionalSettingsParts::Language) {
      setLanguage( pRegionalSettings->language.c_str());
    }
  });

  station.getDisplaySettings()->setHandler([](){
      configureUI(&ui, station.getDisplaySettings());
  });

  updater.setUpdateCallbacks(updateStartHandler,updateProgressHandler,updateFinishedHandler);
  station.setFWUploadCallbacks(fwUploadStartedHandler, fwUploadFinishedHandler);
  station.begin();
  Sensor::setupSensor();  //wait for loading of tempOffset and humOffset first
  WS_DEBUG_RAM("Setup 2");

  setLanguage( pRegionalSettings->language.c_str());
  WS_DEBUG_RAM("Setup 3");
}

void updateData(OLEDDisplay *display, bool firstStart) {
  WS_DEBUG_RAM("UpdateData");
  skipNightScreen = false; //restore night screen mode if skipped
  int i = 3;
  while(wsState & WSState::AppStateUploadingUpdate && i> 0) {
    Serial.println(F("FW upload in progess, waiting 5s"));
    --i;
    delay(5000);
  }

  if (!(wsState & WSState::AppStateNightMode)) {
    digitalWrite( PIN_LED, LOW);
  }

  if (!firstStart) {
    if (influxdbHelper.getWriteSuccess() == 0) { //without any successfull write?
      Serial.println(F("Failed all writes to InfluxDB, restarting!"));
      //TODO: store status to identify reason of restart
      safeRestart();
    }
    Serial.print(F("InfluxDB successful writes: "));
    Serial.println( influxdbHelper.getWriteSuccess());
    influxdbHelper.clearWriteSuccess(); //reset OK counter
  }

  drawUpdateProgress(display, 0, getStr(s_Detecting_location));
  if (station.getRegionalSettings()->detectAutomatically) {
    WS_DEBUG_RAM("Before IPloc");
    station.stopServer();
    WS_DEBUG_RAM("After stop server");
    if(!firstStart) {
      influxdbHelper.release();
      WS_DEBUG_RAM("After cl release");
    }
    delay(1000);
    WS_DEBUG_RAM("After delay");
    //Load location data from IP
    ServicesTracker.updateServiceState(SyncServices::ServiceLocationDetection, ServiceState::SyncStarted);
    ServicesTracker.save();
    int res = detectLocationFromIP(station.getRegionalSettings());
    if(!res) {
      ServicesTracker.updateServiceState(SyncServices::ServiceLocationDetection, ServiceState::SyncFailed);
      if(wsState & WSState::AppStateForceUpdate) {
        //If location detection failed in forced update (probable reason was that automatic detection was turned on)
        safeRestart();
      }
    } else {
      ServicesTracker.updateServiceState(SyncServices::ServiceLocationDetection, ServiceState::SyncOk);
      if(res == 2) {
        station.saveRegionalSettings();
        setLanguage( station.getRegionalSettings()->language.c_str());
      }
    }

    WS_DEBUG_RAM("After IPloc");
    if(!firstStart) {
      influxdbHelper.begin(station.getInfluxDBSettings());
    }
  }

  drawUpdateProgress(display, 10, getStr(s_Updating_time));
  updateTime();


  drawUpdateProgress(display, 20, getStr(s_Checking_update));
  if(firstStart && station.getAdvancedSettings()->updateTime < 2400) {
    ServicesTracker.updateServiceState(SyncServices::ServiceFWUpdate, ServiceState::SyncStarted);
    ServicesTracker.save();
    WS_DEBUG_RAM("Before GH update");
    if(updater.checkUpdate()) {
      ServicesTracker.updateServiceState(SyncServices::ServiceFWUpdate, ServiceState::SyncOk);
    } else {
      ServicesTracker.updateServiceState(SyncServices::ServiceFWUpdate, ServiceState::SyncFailed);
    }
    WS_DEBUG_RAM("After GH update");
  }

  drawUpdateProgress(display, 30, getStr(s_Connecting_IoT_Center));
  if (firstStart) {
    if(conf.iotCenterUrl.length()) {
      // TODO: better solution for updating Settings from IoT center
      auto influxDBSettings = station.getInfluxDBSettings();
      ServicesTracker.updateServiceState(SyncServices::ServiceIoTCenter, ServiceState::SyncStarted);
      ServicesTracker.save();
      if(loadIoTCenter(firstStart, conf.iotCenterUrl, getDeviceID(), influxDBSettings,  conf.iotRefreshMin, station.getRegionalSettings()->latitude, station.getRegionalSettings()->longitude)) {
        ServicesTracker.updateServiceState(SyncServices::ServiceIoTCenter, ServiceState::SyncOk);
        station.getPersistence()->writeToFS(influxDBSettings);
        influxDBSettings->notify();
      } else {
        ServicesTracker.updateServiceState(SyncServices::ServiceIoTCenter, ServiceState::SyncFailed);
      }
    } else {
      influxdbHelper.begin(station.getInfluxDBSettings());
    }
  }

  drawUpdateProgress(display, 50, getStr(s_Updating_weather));
  ServicesTracker.updateServiceState(SyncServices::ServiceCurrentWeather, ServiceState::SyncStarted);
  ServicesTracker.save();
  if(updateCurrentWeather( station.getRegionalSettings(), station.getAdvancedSettings()->openWeatherAPIKey)) {
    ServicesTracker.updateServiceState(SyncServices::ServiceCurrentWeather, ServiceState::SyncOk);
  } else {
    ServicesTracker.updateServiceState(SyncServices::ServiceCurrentWeather, ServiceState::SyncFailed);
  }

  ServicesTracker.updateServiceState(SyncServices::ServiceAstronomy, ServiceState::SyncStarted);
  ServicesTracker.save();
  drawUpdateProgress(display, 60, getStr(s_Calculate_moon_phase));
  if(updateAstronomy( firstStart, station.getRegionalSettings()->latitude, station.getRegionalSettings()->longitude)) {
    ServicesTracker.updateServiceState(SyncServices::ServiceAstronomy, ServiceState::SyncOk);
  } else {
    ServicesTracker.updateServiceState(SyncServices::ServiceAstronomy, ServiceState::SyncFailed);
  }

  drawUpdateProgress(display, 70, getStr(s_Updating_forecasts));
  ServicesTracker.updateServiceState(SyncServices::ServiceForecast, ServiceState::SyncStarted);
  ServicesTracker.save();
  if(updateForecast(station.getRegionalSettings(), station.getAdvancedSettings()->openWeatherAPIKey)) {
    ServicesTracker.updateServiceState(SyncServices::ServiceForecast, ServiceState::SyncOk);
  } else {
    ServicesTracker.updateServiceState(SyncServices::ServiceForecast, ServiceState::SyncFailed);
  }

  ServicesTracker.save(true);

  drawUpdateProgress(display, 80, getStr(s_Connecting_InfluxDB));

  influxdbHelper.update( firstStart, getDeviceID(),  WiFi.SSID(), VERSION, station.getRegionalSettings()->location, station.getRegionalSettings()->useMetricUnits);

  if (firstStart) {
    //Save temperature for the chart
    pSensor->saveTempHist();
  }
  drawUpdateProgress(display, 90, getStr(s_Saving_Status));

  WS_DEBUG_RAM("After updates");

  ServicesTracker.updateServiceState(SyncServices::ServiceDBWriteStatus, ServiceState::SyncStarted);
  ServicesTracker.save();
  if(influxdbHelper.writeStatus()) {
    ServicesTracker.updateServiceState(SyncServices::ServiceDBWriteStatus, ServiceState::SyncOk);
  } else {
    ServicesTracker.updateServiceState(SyncServices::ServiceDBWriteStatus, ServiceState::SyncFailed);
  }
  ServicesTracker.save();
  drawUpdateProgress(display, 100, getStr(s_Done));
  station.startServer();
  WS_DEBUG_RAM("After write status");
  digitalWrite( PIN_LED, HIGH);
}


void loop() {
  station.loop();
  // Needs to be done asynchronously
  if(wsState & WSState::AppStateDrawWifiProgress) {
    drawWifiProgress(&display, VERSION, station.getWifiManager()->getCurrentWiFiNetworkSSID().c_str());
  }
  if(wsState & WSState::AppStateSetupInfluxDB) {
    influxdbHelper.begin(station.getInfluxDBSettings());
    influxdbHelper.update( true, getDeviceID(),  WiFi.SSID(), VERSION, station.getRegionalSettings()->location,station.getRegionalSettings()->useMetricUnits);
    wsState &= ~WSState::AppStateSetupInfluxDB;
  }
  if(!(wsState & WSState::AppStateInitialised)) {
    initData();
  }
  if(wsState & WSState::AppStateSetOffsets) {
    pSensor->resetTempFilter();
    pSensor->resetHumFilter();
    wsState &= ~WSState::AppStateSetOffsets;
  }
  // Ticker function - executed once per minute
  if (((millis() - timeSinceLastUpdate) >= 1000*60) || wsState & WSState::AppStateForceUpdate) {
    if(ui.getUiState()->frameState == FIXED || (wsState & WSState::AppStateNightMode)) {
      WS_DEBUG_RAM("Loop 1");
      if(!(wsState & WSState::AppStateNightMode) && isNightMode(station.getDisplaySettings())) {
        wsState |= WSState::AppStateNightMode;
        skipNightScreen = false;
      } else if((wsState & WSState::AppStateNightMode) && !isNightMode(station.getDisplaySettings())) {
        wsState &= ~WSState::AppStateNightMode;
      }

      timeSinceLastUpdate = millis();
      lastUpdateMins++;
      ServicesTracker.reset();

      if(WiFi.isConnected()) {
        if(station.getAdvancedSettings()->updateTime < 2400) {
          //TODO: change to an alarm like functionality
          time_t tnow = time(nullptr);
          struct tm timeinfo;
          localtime_r(&tnow, &timeinfo);
          uint16_t curtm = timeinfo.tm_hour*100+timeinfo.tm_min;
          if (curtm == station.getAdvancedSettings()->updateTime ) {
            influxdbHelper.release();
            WS_DEBUG_RAM("After release");
            station.stopServer();
            WS_DEBUG_RAM("After stop server");
            ServicesTracker.updateServiceState(SyncServices::ServiceFWUpdate, ServiceState::SyncStarted);
            ServicesTracker.save();
            WS_DEBUG_RAM("Before GH update");
            if(updater.checkUpdate()) {
              ServicesTracker.updateServiceState(SyncServices::ServiceFWUpdate, ServiceState::SyncOk);
            } else {
              ServicesTracker.updateServiceState(SyncServices::ServiceFWUpdate, ServiceState::SyncFailed);
            }
            WS_DEBUG_RAM("After GH update");
            station.startServer();
            WS_DEBUG_RAM("After start server");
            influxdbHelper.begin(station.getInfluxDBSettings());
            influxdbHelper.update( false, getDeviceID(),  WiFi.SSID(), VERSION, station.getRegionalSettings()->location, station.getRegionalSettings()->useMetricUnits);
          }
        }

        //Sync IoT Center configuration
        if (lastUpdateMins % conf.iotRefreshMin == 0 && conf.iotCenterUrl.length()) {
          if (!(wsState & WSState::AppStateNightMode)) {
            digitalWrite( PIN_LED, LOW);
          }
          // TODO: better solution for updating Settings from IoT center
          auto influxDBSettings = station.getInfluxDBSettings();
          ServicesTracker.updateServiceState(SyncServices::ServiceIoTCenter, ServiceState::SyncStarted);
          ServicesTracker.save();
          if(loadIoTCenter(false, conf.iotCenterUrl, getDeviceID(), influxDBSettings, conf.iotRefreshMin, station.getRegionalSettings()->latitude, station.getRegionalSettings()->longitude)) {
            ServicesTracker.updateServiceState(SyncServices::ServiceIoTCenter, ServiceState::SyncOk);
            station.getPersistence()->writeToFS(influxDBSettings);
            influxDBSettings->notify();
          } else {
            ServicesTracker.updateServiceState(SyncServices::ServiceIoTCenter, ServiceState::SyncFailed);
          }
          ServicesTracker.save();
          digitalWrite( PIN_LED, HIGH);
        }


        //Update data?
        if (lastUpdateMins % station.getAdvancedSettings()->updateDataInterval == 0 || wsState & WSState::AppStateForceUpdate) {
          if (!(wsState & WSState::AppStateNightMode)) {
            digitalWrite( PIN_LED, LOW);
          }
          if(wsState & WSState::AppStateForceUpdate) {
            // Delay update to let server connection settle
            delay(1000);
          }
          updateData(&display,false);
          digitalWrite( PIN_LED, HIGH);
          wsState &= ~WSState::AppStateForceUpdate;
        }

        if(influxdbHelper.wasReleased()) {
          influxdbHelper.begin(station.getInfluxDBSettings());
          influxdbHelper.update( false, getDeviceID(),  WiFi.SSID(), VERSION, station.getRegionalSettings()->location, station.getRegionalSettings()->useMetricUnits);
        }


        //Write into InfluxDB
        if (lastUpdateMins % station.getInfluxDBSettings()->writeInterval == 0) {
          if (!(wsState & WSState::AppStateNightMode)) {
            digitalWrite( PIN_LED, LOW);
          }
          pSensor->saveTempHist();  //Save temperature for the chart
          ESP.wdtFeed();
          int i=3;
          while(station.isRequestInProgress() &&  i > 0 ) { 
            Serial.println(F(" HTTP req in progress, delaying write"));
            delay(500); 
            --i;
          }

          if(time(nullptr) < 1000000000ul) { 
            Serial.println(F("Time is not synced, trying update"));
            updateTime();
          }
          ServicesTracker.updateServiceState(SyncServices::ServiceDBWriteData, ServiceState::SyncStarted);
          ServicesTracker.save();
          //always save in celsius
          unsigned long start = millis();
          bool writeStatus = influxdbHelper.write( Sensor::tempF2C( pSensor->getTempF()), pSensor->getHum(), station.getRegionalSettings()->latitude, station.getRegionalSettings()->longitude);
          if(writeStatus) {
            ServicesTracker.updateServiceState(SyncServices::ServiceDBWriteData, ServiceState::SyncOk);
          } else {
            ServicesTracker.updateServiceState(SyncServices::ServiceDBWriteData, ServiceState::SyncFailed);
          }
          ServicesTracker.save();
          Serial.print(F("InfluxDB write "));
          uint32_t writeTime = millis() - start;
          Serial.println(String(writeTime) + String(F("ms")));
          digitalWrite( PIN_LED, HIGH);
          WS_DEBUG_RAM("After write");
          if(!writeStatus && influxdbHelper.statusCode() == HTTPC_ERROR_READ_TIMEOUT) {
            Serial.println(F("Restarting influxdb client"));
            influxdbHelper.release();
            influxdbHelper.begin(station.getInfluxDBSettings());
            WS_DEBUG_RAM("After influxdb client restart");
          }
        }
      }
      if(!station.isServerStarted()) {
        station.startServer();
      }
    } 
  } 

  //Handle BOOT button
  unsigned int loops = 0;
  while (digitalRead(PIN_BUTTON) == LOW) {  //Pushed boot button?
    if (loops == 0) {
      if(wsState & WSState::AppStateNightMode) {
        skipNightScreen ^= 1; //flip skip night screen status
        if (skipNightScreen) {
          nextUIUpdate = 0; //reset counter to show immediately standard screens
        }
      }
      Serial.println( F("Button BOOT"));
      if(!(wsState & WSState::AppStateAPRunning)) {
        ui.nextFrame();   //jump to the next frame
      } else {
        drawAPInfo(&display, station.getWifiManager()->getAPInfo());
      }
    }
    if ((loops > 4) || (wsState & WSState::AppStateAPRunning)) {
      showConfiguration(&display, (200 - loops) / 10, VERSION, timeSinceLastUpdate + (station.getAdvancedSettings()->updateDataInterval - ((lastUpdateMins % station.getAdvancedSettings()->updateDataInterval)) * 60 * 1000), getDeviceID(), &influxdbHelper);  //Show configuration after 0.5s
    }

    loops++;
    if (loops > 200) {  //factory reset after 20 seconds
      station.getPersistence()->removeConfigs();
      safeRestart();
    }

    delay(100);
  }
  if (wsState & WSState::AppStateAPRunning) {
    drawAPInfo(&display, station.getWifiManager()->getAPInfo());
  }

  if (wsState & WSState::AppStateInitialised && !(wsState & WSState::AppStateAPRunning) && (!nextUIUpdate || (int(nextUIUpdate - millis()) <= 0))) {
    ESP.wdtFeed();
    int remainingTimeBudget = DEFAULT_DELAY;
    if (skipNightScreen || !(wsState & WSState::AppStateNightMode)) {
      remainingTimeBudget = ui.update();
      nextUIUpdate = millis() + remainingTimeBudget;
    } else {
      drawNight(&display, station.getDisplaySettings());
      nextUIUpdate = millis() + getRemainingSecsTillMinute()*1000;
    }
    // reached basic bussiness loop end
    ServicesTracker.clearResetCount();
    delay(max(min(remainingTimeBudget, DEFAULT_DELAY),0));
  } else
    delay(DEFAULT_DELAY);
}

uint8_t getRemainingSecsTillMinute() {
  time_t now = time(nullptr);
  struct tm *timeInfo = localtime(&now);
  return (60 - timeInfo->tm_sec) + 1;
}

bool isInfluxDBError() {
  return influxdbHelper.isError();
}
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

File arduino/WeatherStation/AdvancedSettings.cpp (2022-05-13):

#include "AdvancedSettings.h"
#include "ScreenCommon.h"
#include "Sensor.h"
#include "WeatherStation.h"
#include "Tools.h"

#define ADVANCED_DEFAUT_UPDATE_INTERVAL 60
//See https://docs.thingpulse.com/how-tos/openweathermap-key/
#define ADVANCED_DEFAUT_OPENWEATHER_API_KEY ""
#define ADVANCED_DEFAUT_NTP_SERVERS "pool.ntp.org,time.nis.gov,time.google.com"
#define ADVANCED_DEFAUT_TEMPERATURE_OFFSET 0.0
#define ADVANCED_DEFAUT_HUMIDITY_OFFSET 0.0
#define ADVANCED_DEFAULT_OWNER F("bonitoo-io")
#define ADVANCED_DEFAULT_REPO F("weather-station")
#define ADVANCED_DEFAULT_BIN_FILE F("ws-firmware-%version%.bin")
#define ADVANCED_DEFAULT_MD5_FILE F("ws-firmware-%version%.md5")
#define ADVANCED_DEFAULT_UPDATETIME 300 //HHMM
#define ADVANCED_DEFAULT_CHECKBETA  false
#define ADVANCED_DEFAULT_VERIFY_CERT  false
#define ADVANCED_FLOAT_MIN_DIFF 0.001

#include "custom_dev.h"

const char *OpenweatherApiKeyStr PROGMEM = "openWeatherAPIKey";

static uint16_t getDefaultUpdateTime() {
  uint8_t mac[6];
  wifi_get_macaddr(STATION_IF, mac);
  return ADVANCED_DEFAULT_UPDATETIME + mac[5];
}

AdvancedSettings::AdvancedSettings():
  updateDataInterval(ADVANCED_DEFAUT_UPDATE_INTERVAL),
  ntpServers(F(ADVANCED_DEFAUT_NTP_SERVERS)),
  owner(ADVANCED_DEFAULT_OWNER),
  repo(ADVANCED_DEFAULT_REPO),
  binFile(ADVANCED_DEFAULT_BIN_FILE),
  md5File(ADVANCED_DEFAULT_MD5_FILE),
  checkBeta(ADVANCED_DEFAULT_CHECKBETA),
  verifyCert(ADVANCED_DEFAULT_VERIFY_CERT),
  updatedParts(0)  {
  setUpdateTime(getDefaultUpdateTime());
  DECLARE_ENCRYPT_STR( owKeyStr, ADVANCED_DEFAUT_OPENWEATHER_API_KEY);
  openWeatherAPIKey = GET_ENCRYPT_STR(owKeyStr);
}

void AdvancedSettings::begin() {
  _eepromData.begin();
  if(_eepromData.read() != 0) {  //read error? load default values
    _eepromData.setTempOffsetRaw(ADVANCED_DEFAUT_TEMPERATURE_OFFSET);
    _eepromData.setHumOffsetRaw(ADVANCED_DEFAUT_HUMIDITY_OFFSET);
  }
}

void AdvancedSettings::setUpdateTime(uint16_t time) {
  uint8_t h = time/100;
  uint8_t m = time%100;
  if(m >= 60) {
    ++h;
    m = m - 60;
    time = h*100+m;
  }
  updateTime = time;
}

void AdvancedSettings::print(const __FlashStringHelper *title) {
    Serial.print(title);
    Serial.print(F(" updateDataInterval: "));Serial.print(updateDataInterval);
    Serial.print(F(", openWeatherAPIKey: "));Serial.print(obfuscateToken(openWeatherAPIKey));
    Serial.print(F(", ntpServers: "));Serial.print(ntpServers);
    Serial.print(F(", tempOffset: "));Serial.print(_eepromData.getTempOffsetRaw());
    Serial.print(F(", humOffset: "));Serial.print(_eepromData.getHumOffsetRaw());
    Serial.print(F(", owner: "));Serial.print(owner);
    Serial.print(F(", repo: "));Serial.print(repo);
    Serial.print(F(", binFile: "));Serial.print(binFile);
    Serial.print(F(", md5File: "));Serial.print(md5File);
    Serial.print(F(", updateTime: "));Serial.print(updateTime);
    Serial.print(F(", checkBeta: "));Serial.print(checkBeta);
    Serial.print(F(", verifyCert: "));Serial.print(verifyCert);
    Serial.println();
}

int AdvancedSettings::save(JsonObject& root) {
    root[F("updateDataInterval")] = updateDataInterval;
    root[FPSTR(OpenweatherApiKeyStr)] = openWeatherAPIKey;
    root[F("ntpServers")] = ntpServers;
    root[F("owner")] = owner;
    root[F("repo")] = repo;
    root[F("binFile")] = binFile;
    root[F("md5File")] = md5File;
    root[F("updateTime")] = updateTime;
    root[F("checkBeta")] = checkBeta;
    root[F("verifyCert")] = verifyCert;

    print(F("Save Advanced settings"));
    return 0;
}

int AdvancedSettings::load(JsonObject& root) {
  updateDataInterval = root[F("updateDataInterval")];
  openWeatherAPIKey = root[FPSTR(OpenweatherApiKeyStr)].as<const char *>();
  ntpServers = root[F("ntpServers")].as<const char *>();
  owner = root[F("owner")] | String(ADVANCED_DEFAULT_OWNER);
  repo = root[F("repo")] | String(ADVANCED_DEFAULT_REPO);
  binFile = root[F("binFile")] | String(ADVANCED_DEFAULT_BIN_FILE);
  md5File = root[F("md5File")] | String(ADVANCED_DEFAULT_MD5_FILE);
  setUpdateTime(root[F("updateTime")] | getDefaultUpdateTime());
  checkBeta = root[F("checkBeta")];
  verifyCert = root[F("verifyCert")] | ADVANCED_DEFAULT_VERIFY_CERT;

  print(F("Load Advanced settings"));
  return 0;
}

void AdvancedSettings::updateEEPROMData( float tempOffset, float humOffset) {
  setTempOffset(tempOffset);
  setHumOffset(humOffset);
  _eepromData.write();
}

float AdvancedSettings::getTempOffsetF() {
  return _eepromData.getTempOffsetRaw();
}

float AdvancedSettings::getTempOffset() {
  return station.getRegionalSettings()->useMetricUnits ? getTempOffsetF() / 9.0 * 5.0 : getTempOffsetF(); //convert from F to C if needed
}

float AdvancedSettings::getHumOffset() {
  return _eepromData.getHumOffsetRaw();
}

void AdvancedSettings::setTempOffset( float tempOffset) {
  _eepromData.setTempOffsetRaw( station.getRegionalSettings()->useMetricUnits ? tempOffset * 9.0 / 5.0 : tempOffset); //convert from F to C if needed
}
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

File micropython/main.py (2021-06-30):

from influxdb2 import Point, Client, WritePrecision
from wm import WifiManager
from machine import Pin, I2C, reset
from ssd1306 import SSD1306_I2C
from dht import DHT11
from micropython import const
import ntptime
import gc

try:
    from urandom import getrandbits
    import utime as time
    import uasyncio as asyncio
except:
    from random import getrandbits
    import time
    import asyncio

INTERVAL_MS = CFG['config']['interval']
NTP_INTERVAL = CFG['config']['ntp_interval']
OLED_WIDTH = const(128)
OLED_HEIGHT = const(64)
TEXT_SIZE = {'x': const(8), 'y': const(8)}
Y_SPACING = const(6)
oled = None
i2c = None
dht11 = None
led2 = None
loop = None


def show_text_line(x, y, text, c=1, timeout=0):
    if c == 0:
        fill_c = 1
    else:
        fill_c = 0
    oled.text(text, x, y, c)
    oled.show()
    if timeout > 0:
        time.sleep(timeout)
        oled.fill_rect(x, y, (TEXT_SIZE['x'] * len(text)), TEXT_SIZE['y'], fill_c)
    else:
        return (x, y, TEXT_SIZE['x'] * len(text), TEXT_SIZE['y'], fill_c)


def set_rtc(host):
    # if needed, overwrite default time server
    ntptime.host = host

    try:
        print('UTC time before sync：{0}'.format(time.gmtime()))
        # make sure to have internet connection
        ntptime.settime()
        print('UTC time after sync：{0}'.format(time.gmtime()))
    except:
        print('Error syncing time.')


def clear_text_line(rect):
    oled.fill_rect(*rect)


def init():
    global i2c, oled, led2, dht11
    # init buses
    i2c = I2C(scl=Pin(14), sda=Pin(2), freq=400000)
    oled = SSD1306_I2C(OLED_WIDTH, OLED_HEIGHT, i2c, addr=0x3c)
    oled.rotate(False)
    show_text_line(12, 30, 'InfluxData WS', 1, 3)
    # init devices
    line = show_text_line(5, 30, 'Initialize', 1)
    led2 = Pin(4, Pin.OUT)
    dht11 = DHT11(Pin(5))
    clear_text_line(line)
    show_text_line(5, 30, 'Connecting WiFi', 1)


def randrange(start, stop=None):
    if stop is None:
        stop = start
        start = 0
    upper = stop - start
    bits = 0
    pwr2 = 1
    while upper > pwr2:
        pwr2 <<= 1
        bits += 1
    while True:
        r = getrandbits(bits)
        if r < upper:
            break
    return r + start


def restart():
    time.sleep(10)
    reset()


def get_t_rh():
    dht11.measure()
    t = dht11.temperature()  # eg. 23 (°C)
    h = dht11.humidity()  # eg. 41 (% RH)
    return t, h


async def show_data(screens):
    paging_ms = INTERVAL_MS // len(screens) - const(1000)
    oled.fill(0)
    for screen, lines in screens.items():
        y_max = OLED_HEIGHT - ((Y_SPACING * (len(lines) - 1)) + (TEXT_SIZE['y'] * len(lines)))
        x_random = randrange(0, OLED_WIDTH - len(screens[screen][0]) * TEXT_SIZE['x'])
        y_random = randrange(0, y_max)
        if y_max < 0:
            raise ValueError('More lines than display can handle')
        else:
            for num, line in enumerate(lines, start=0):
                x = x_random
                y = y_random + (Y_SPACING * num) + (TEXT_SIZE['y'] * num)
                oled.text(line, x, y)
            oled.show()
            if paging_ms < INTERVAL_MS:
                await asyncio.sleep_ms(paging_ms)
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

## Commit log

2021-05-05 Add the first arduino code version
2021-05-05 Fix DHT11 sensor reading - 2 seconds
    [WeatherStation.ino]
2021-05-05 Weather location updated, temperature updated in header
2021-05-11 Add board installation
2021-05-11 Add BOOT button support
2021-05-11 Fix analog clock sliding
    [WeatherStation.ino]
2021-05-12 Add DeviceID support for InfluxDB, reset via button support & small improvements
    [WeatherStation.ino]
2021-05-13 Add watchdog, reset message
    [WeatherStation.ino]
2021-05-14 Add clientID tag, updated device tag
2021-05-18 Add automatic 12/24 hours detection Add automatic location detection Add utf-8 language support for weather forecast Better logging Updated OLED header/footer (Out temperature, wifi signal) Fixed UTC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
    [WeatherStation.ino, utf8ascii.cpp]
2021-05-19 Add LED support - when communicates and InfluxDB error status on OLED
    [WeatherStation.ino]
2021-05-20 Add Moon phases screen Global variable names refactoring Add hostname for Wifi Add location to actual whather screen Add warning icon when influxdb error Add uptime in config screen Add Influxdb reco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
    [WeatherStation.ino]
2021-05-21 feat(case): add the first prototype
    [case.scad]
2021-05-23 Improve stability of location Update Configuration page UI Update Wifi signal level calculation
    [WeatherStation.ino]
2021-05-23 Add tag Version into influxdb Reuses connection for influxdb Improved logging Redesigned moon phases - changed library
    [WeatherStation.ino]
2021-05-23 Fixed moon icon phases
    [WeatherStation.ino]
2021-05-24 Add wind screen Reformated astro screen Add heat index to INDOOR screen Add wind to current weather screen Add min/max temperature to current weather screen
2021-05-25 feat(case): harden pilars, improve display adapter
    [case.scad]
2021-05-25 fix(design): remove middle hole
    [case.scad]
2021-05-25 fix: rollback h variable
    [case.scad]
2021-05-30 fix(linux): Tools.h must be case sensitive
    [ScreenClock.cpp, ScreenCommon.cpp, ScreenWeather.cpp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]
2021-05-31 fix: bugs, readme and better code
    [influxdb2.py, main.py, wm.py]
2021-05-31 Add date format handling & small fixes
    [Location.cpp, ScreenWeather.cpp, Tools.cpp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]
2021-06-01 fix: further optimization, update README.md
    [main.py]
2021-06-04 Add sensor temperature and humidity offset calibration option
2021-06-04 fix: lowercase lat and lon, fix SFO GPS location
    [logoInfluxdata.scad]
2021-06-08 Refactor reduced memory, fix default TZ
    [ScreenCommon.cpp, WeatherStation.ino]
2021-06-08 Fixed wrong wind direction arrow
    [ScreenCommon.cpp, ScreenWeather.cpp, WeatherStation.ino]
2021-06-08 Add WiFI tag int InfluxDB Removed Wifi network from deviceID Refactored memory saving
2021-06-09 Improve chart - min max calculation Removed caching from DHT sensor Add indoor temperature history saving
2021-06-09 Add Line chart shows real temperature history - 96 minutes
2021-06-09 Finished temperature line chart Saving history for 90 minutes Fixed temperature history saving
    [LineChart.cpp, ScreenCommon.cpp, WeatherStation.ino]
2021-06-10 Add load temperature history from influxdb after start
2021-06-10 Y axis scale improved
2021-06-15 fix: add webrepl_cfg.py, rotate display, update README.md
    [main.py]
2021-06-15 fix: Reconfigure InfuxDB works
    [InfluxDBHelper.cpp, Location.cpp, WeatherStation.ino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]
2021-06-16 Update Temp history uses native unit - more accurate Boot button causes factory reset instead of reset after 20s Updated czech translation Fixed time offset loading order Updated warning icon
    [InfluxDBHelper.cpp, LineChart.cpp, ScreenCommon.cpp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]
2021-06-17 Added TemperatureUnit tad and now string in the line chart
2021-06-18 feat: updating from github, arduino json 6.18 comp, wifi establishing improved
2021-06-18 fix: synctime after detecting timezone
    [WeatherStation.ino]
2021-06-28 feat: Add device ID to About screen
2021-06-29 fix: long date format
    [InfluxDBHelper.cpp, ScreenCommon.cpp, Tools.cpp]
2021-06-30 fix: strings, some sleep after OSError
    [influxdb2.py, main.py]
2021-06-30 fix: releasing influxdb client before memory hungry routines (#12)
    [InfluxDBHelper.cpp, Updater.cpp, WeatherStation.cpp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]
2021-06-30 fix: Proper handling when forecast API call fails
    [ScreenCommon.cpp, ScreenWeather.cpp, Tools.cpp]
2021-06-30 fix: sun rise/set calculation when forecast fails
    [ScreenCommon.cpp, ScreenWeather.cpp, Tools.cpp]
2021-06-30 fix: improved forecast processing
    [ScreenWeather.cpp]
2021-07-01 fix: correct heap fragmentation column name
    [InfluxDBHelper.cpp]
2021-07-01 fix: reducing initial wifi connection attempts
    [WiFi.cpp, WiFi.h]
2021-07-27 fix: improved wifi wizard
    [ScreenCommon.cpp, Tools.cpp, WeatherStation.ino]
2021-07-27 fix: reduced weather logging, moved strings into flash memory
    [ScreenWeather.cpp, WeatherStation.ino]
2021-07-28 fix: add update logging
    [ScreenCommon.cpp]
2021-07-28 fix: removed password/token from logging
    [InfluxDBHelper.cpp, WiFi.cpp]
2021-09-08 fix: Oled wifi progress flickering when WiFi is not available
    [WeatherStation.ino]
2021-09-16 fix: Changing WiFi migration from rename to write and delete
    [FSPersistance.cpp]
2021-09-22 feat: connect to saved network from scanner page, overall connection failure improvement
    [WeatherStation.cpp, WiFi.cpp, WiFi.h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]
2021-09-29 fix: unifying built time
    [WeatherStation.ino]
2021-09-29 fix: null values of tem and hum in first minute
    [WeatherStation.ino]
2021-10-01 fix: initial language setting
    [WeatherStation.ino]
2021-10-08 feat: advanced settings, various web UI fixes
    [AdvancedSettings.cpp, InfluxDBHelper.cpp, Location.cpp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]
2021-10-08 fix: display WiFi network name, when known, when conecting
    [WeatherStation.ino, WiFi.cpp, WiFi.h]
2021-10-12 fix: occassional crash when saving regional settings
    [WeatherStation.ino]
2021-11-24 fix: registering change of UTC offset always
    [Location.cpp]
2021-11-24 feat: reporting wifi disconnect count fix: saving memory by disabling retrying
    [InfluxDBHelper.cpp, WeatherStation.ino, WiFi.cpp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]
2021-11-30 fix: tuning write params - set higher HTTP timeout, batchsize 2
    [InfluxDBHelper.cpp]
2022-01-06 fix: update to final model, needs review/transl
    [case.scad, logoInfluxdata.scad]
2022-01-10 fix: incorrect values when temp sensor is not connected
    [Tools.cpp]
2022-01-10 feat: 2-color OLED support, fix: temp sensor error handling
    [LineChart.cpp, ScreenClock.cpp, ScreenCommon.cpp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]
2022-01-10 fix: sensor error message
2022-01-27 refactor: changed PIN macro names
2022-01-27 fix: color OLED messages & fixed memory error issue
    [InfluxDBHelper.cpp, LineChart.cpp, ScreenCommon.cpp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]
2022-01-27 feat: humidity sensor offset autocalibration
2022-01-27 fix: enabled ip loc detection always updates country dependent settings
    [Location.cpp]
2022-01-27 fix: NO_VALUE int value issue - fixed line chart
    [LineChart.cpp, ScreenWeather.cpp]
2022-01-28 fix: updated czech waiting message on init screen
    [Tools.cpp]
2022-01-28 feat: automatic reboot when no write to InfluxDB is successful
    [InfluxDBHelper.cpp, WeatherStation.ino]
2022-01-28 feat: ignore temp/hum spikes from sensor
2022-02-03 fix: hum autocalibration was ignored, some string fixes
    [Tools.cpp]
2022-02-03 fix: invalid number in status line weather forecast error, improved handling of cached values for DHT
    [Tools.cpp, WeatherStation.ino]
2022-02-10 fix: hanling disconnected wifi during test, restarting after initial config
    [WiFi.cpp, WiFi.h]
2022-02-11 fix: Take account of invalid sensor values
2022-02-12 refactor: redesigned temp/hum sensor handling - ready for new sensors
    [InfluxDBHelper.cpp, LineChart.cpp, ScreenCommon.cpp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]
2022-02-14 feat: Add STHC3 sensor support
2022-02-14 fix: improved sensor error logging
    [Sensor.cpp]
2022-02-15 fix: DHT11 sensor humidity timeout, names refactoring, influxdb sensor reporting
    [InfluxDBHelper.cpp, Sensor.cpp, SensorDHT.cpp]
2022-02-22 fix: responding to internal urls with index
    [WeatherStation.cpp]
2022-02-22 fix: alowing switch to AP info screen when button is pressed
    [WeatherStation.ino]
2022-02-22 fix: improved WiFi settings behavior
    [WiFi.cpp, WiFi.h]
2022-02-22 fix: humidity offset calculation
    [Sensor.cpp]
2022-02-25 feat: add warning icon to setup screen when sensor error
    [ScreenCommon.cpp, WeatherStation.ino]
2022-02-26 fix: Improved initial WiFi conn experience
    [UploadFirmware.cpp, WeatherStation.ino, WiFi.cpp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]
2022-02-28 fix: improved error handling of InfluxDB writes
    [InfluxDBHelper.cpp]
2022-03-02 chore: switching speed to 115200 to see exception detail during run
2022-03-02 fix: fallback for shutting AP after successful connection
    [WiFi.cpp, WiFi.h]
2022-03-02 fix: replacing whole wifi password by stars
    [WiFiSettings.cpp]
2022-03-02 fix: properly setting up influxdb client after release
    [InfluxDBHelper.cpp, WeatherStation.ino]
2022-03-03 fix: Disconnect WiFi before restart
    [WeatherStation.ino, WiFi.cpp]
2022-03-03 feat: show sensor error during wifi connection
    [InfluxDBHelper.cpp, ScreenCommon.cpp, WeatherStation.ino]
2022-03-06 fix: take account also final version for comparison
    [Updater.cpp]
2022-03-07 fix: skipping the same version for update
    [Updater.cpp]
2022-03-08 fix: Using full range of strings comparision result
    [Updater.cpp]
2022-03-08 feat: new 3d printer box model for batch 2203
    [case.scad, logoInfluxdata.scad]
2022-03-10 docs: Add button logging
2022-03-10 feat: Improved debug screen after pressing button
2022-03-11 feat: Added delay when resets occurs repeatedly
    [InfluxDBHelper.cpp, ServiceState.cpp, Tools.cpp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]
2022-03-15 fix: trying update weather info 3x times
    [ScreenWeather.cpp]
2022-03-28 fix: non-latin languages are showing ???? in weather message - forced to English
    [Location.cpp, RegionalSettings.cpp, ScreenWeather.cpp]
2022-04-06 fix: fixing incomlete wifi networks list
    [WiFi.cpp]
2022-04-06 fix: server start checking
    [WeatherStation.cpp, WeatherStation.ino]
2022-04-07 feat: add night screen support (missing webpage config support) and fixed nextUIUpdate type
    [DisplaySettings.cpp, WeatherStation.ino]
2022-04-07 fix: updated Lat and Lon field names according to IoT center
    [InfluxDBHelper.cpp]
2022-04-07 fix: streamed wifi list
    [WiFi.cpp, WiFi.h]
2022-04-08 fix: faster reconnect on AP assoc problems
    [WiFi.cpp]
2022-04-11 feat: initial boot shows raw temperature and humidity in config screen
2022-04-12 fix: button is 1mm longer
    [case.scad]
2022-04-20 feat: added sensor type to About
2022-04-21 feat: added sensor calibration dialog
2022-04-21 fix: trying to fix rarely occuring timeout of save advanced settings
    [WeatherStation.ino]
2022-04-25 feat: delay in main loop to reduce heat from CPU, refactored temp/hum offset
2022-04-25 chore: renamed driverGetTempF method
2022-04-25 fix: obfuscate validation token
    [InfluxDBHelper.cpp]
2022-04-25 chore: add must-revalidate to fix over-caching in Chrome
    [WeatherStation.cpp]
2022-04-27 feat: Support SHTxx sensors family (autodetect)
2022-04-27 fix: occasionally wifi scanning error
    [WiFi.cpp]
2022-04-27 feat: restart on failed location detection during forced update
    [WeatherStation.ino]
2022-04-28 fix: fast sensor offset propagation
    [AdvancedSettings.cpp, Sensor.cpp]
2022-05-05 fix: solved NAN temeprature issues & removed SDHT library depedency
    [Sensor.cpp, SensorDHT.cpp]
2022-05-05 chore: improved temperature and humidity transformation
2022-05-06 fix: correctly reporting when WiFi is connected
    [WiFi.cpp]
2022-05-06 fix: don't write if HTTP connection are in progress
    [WeatherStation.cpp, WeatherStation.ino]
2022-05-06 fix: properly print token part
    [InfluxDBHelper.cpp]
2022-05-06 fix: slowdown wifi management when no known networks
    [WiFi.cpp]
2022-05-11 fix: run yield after enabled interrupts
2022-05-11 feat: Use GPS for weather service when location fails
    [ScreenWeather.cpp]
2022-05-12 fix: add proper variable initialization
    [Sensor.cpp]
2022-05-12 fix: add internal variable initialization
    [SensorDHT.cpp]
2022-05-12 fix: improved utf8 conversion (reduced memory fragmentation, removed global variable)
    [Tools.cpp]
2022-05-12 fix: proper routes model (fixes mem leak)
    [WeatherStation.cpp]
2022-05-12 fix: trying higher memory limit to fix occasionaly bad response
    [WeatherStation.cpp]
2022-05-12 fix: fixed occasinally not found registered endpoint
    [WeatherStation.cpp]
2022-05-12 fix: reseting sensor filter on the mainloop to prevent crash
    [AdvancedSettings.cpp, WeatherStation.ino]
2022-05-13 fix: store offsets only if changed
    [AdvancedSettings.cpp]
2022-05-13 fix: properly clearing flags
    [WeatherStation.ino]
2022-05-24 fix: improved wifi settings persistance to allow wifi with name with slash char
    [FSPersistance.cpp, WeatherStation.cpp, WiFi.cpp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]
2022-05-27 fix: ensuring all updates work in night mode
    [WeatherStation.cpp, WeatherStation.ino]
2022-06-16 chore(deps): bump async in /arduino/WeatherStation/interface
    Bumps [async](https://github.com/caolan/async) from 2.6.3 to 2.6.4.
    - [Release notes](https://github.com/caolan/async/releases)
    - [Changelog](https://github.com/caolan/async/blob/v2.6.4/CHANGELOG.md)
    - [Commits](https://github.com/caolan/async/compare/v2.6.3...v2.6.4)
    ---
    updated-dependencies:
    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
2022-06-17 chore(deps): bump eventsource in /arduino/WeatherStation/interface
    Bumps [eventsource](https://github.com/EventSource/eventsource) from 1.1.0 to 1.1.2.
    - [Release notes](https://github.com/EventSource/eventsource/releases)
    - [Changelog](https://github.com/EventSource/eventsource/blob/master/HISTORY.md)
    - [Commits](https://github.com/EventSource/eventsource/compare/v1.1.0...v1.1.2)
    - dependency-name: eventsource
    dependency-type: indirect
    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
2022-06-17 chore(deps): bump minimist in /arduino/WeatherStation/interface
    Bumps [minimist](https://github.com/substack/minimist) from 1.2.5 to 1.2.6.
    - [Release notes](https://github.com/substack/minimist/releases)
    - [Commits](https://github.com/substack/minimist/compare/1.2.5...1.2.6)
    - dependency-name: minimist
    ...
    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
2022-06-17 chore(deps): bump url-parse in /arduino/WeatherStation/interface
    Bumps [url-parse](https://github.com/unshiftio/url-parse) from 1.5.4 to 1.5.10.
    - [Release notes](https://github.com/unshiftio/url-parse/releases)
    - [Commits](https://github.com/unshiftio/url-parse/compare/1.5.4...1.5.10)
    - dependency-name: url-parse
    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
2022-06-17 chore(deps): bump nanoid in /arduino/WeatherStation/interface
    Bumps [nanoid](https://github.com/ai/nanoid) from 3.1.30 to 3.3.4.
    - [Release notes](https://github.com/ai/nanoid/releases)
    - [Changelog](https://github.com/ai/nanoid/blob/main/CHANGELOG.md)
    - [Commits](https://github.com/ai/nanoid/compare/3.1.30...3.3.4)
    - dependency-name: nanoid
    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
2022-08-10 fix: correct string type for %s
    [Tools.cpp]
